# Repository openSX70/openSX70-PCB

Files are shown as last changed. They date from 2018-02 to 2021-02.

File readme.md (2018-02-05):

+ ## **What is openSX70?**

It is many things at once, but simply put, openSX70 is an open source (hardware and software) project that aims to take the SX70 beyond what is possible now in a cheap and non destructive way. 

Its main project at the moment is to make an [Arduino](https://www.arduino.cc/)-based replacement PCB (ECM in Polaroid lingo, and corresponding Arduino code to gain manual camera control, allow for double exposures, Bluetooth control and much more.
At the same time the project aims to be a hub of all things SX70 related, with documents concerning tips, repairs or hacks, like the electronic modification of your camera to accept 600-ISO film. There are other web pages about the SX70, but most seem to be abandoned. We would like to compile as many as possible resources.

+ ## **What does an openSX70 camera that a regular SX70 doesn't?**

In a nutshell: manual control of the camera:
 
 -  Manual shutter speed control. Within the limits of the camera (around 1/175th)
 -  Double/Multiple exposures.
 -  B (Bulb) mode.
 -  T mode.
 -  PC flash connector.
 -  f.8 (maximum aperture) flash operation.
 -  Optional delayed mirror operation (to avoid vibrations).
 -  Built-in shutter delay (long press on red button).
 -  Built-in optional light meter.
+ ## **Where is openSX70?**

 This is our [main webpage and repository of files](www.opensx70.com). We also have [Facebook group](https://www.facebook.com/groups/739071666267626/ "Facebook openSX70 group"). We are also on instagram and Twitter. The code and files are in [Github](https://github.com/openSX70).

+ ## **But, hasn’t this already been done?**

Yes… and no. There are at least two awesome commercial projects that accomplish something quite similar. I recommend them both. But this is the first open source project.

+ ## **So openSX70 is a product?**

Again, yes and no, since it is an open project anyone will be able to make his own pcb (as long as it has no commercial purpose).
Since we recognize that disassembling an SX70 and replacing the board is not for the faint of heart, if the project is successful and there is interest we might set up a network of associates that will do it for you. That would help us gain economies of scale, and, cover operating costs. Once the pcb is in the camera you will be able to reprogram it fairly easily as many times as you want.

+ ## **Ok, I like it, how can I get one?**

Please bear in mind that openSX70 is not a product as such, and will probably never be. Think of it as an ever improving experimental platform. As an open project, it is basically free as long as you use for non commercial purposes under [Creative Commons "Attribution-NonCommercial 4.0 International (CC BY-NC 4.0)"](https://creativecommons.org/licenses/by-nc/4.0/)
Since the process of replacement of the SX70 board is not trivial, you need special tools, and you can damage the camera in the process, parts as such will probably never be sold to general public. The board replacement is non-destructive but has to be done carefully. **See previous question about openSX70 as as product**.

+ ## **So then… how "far" ahead is the project now?**

We are quite ahead in development. We have successfully replaced the ECM of an alpha camera with an external prototype board: the“FrankenSX70”. Then we have prototyped the external control dongle. Now the electronic schematics of both the main circuit and the dongle are more or less finalised and also a preliminary design of the board has been done and some prototypes have been ordered.
For a quick reference of the status check the project page.

We are also trying to replicate and make more affordable some of the special tools needed to open and fix the SX70, and find replacements and alternatives of critical parts.

+ ## **Can I help?**

YES! We need your help, join us!
We want **YOU** to join us on the openSX70 project in any capacity that you wish, we need your help, we have to set up the openSX70 portal, we need arduino and microcontroller programmers, we need help designing the PCB, and above all, we need enthusiasts to join and build a community to propagate the project!

We want to encourage and **support** for similar commercial products and services already on the market, but specially the dedicated people that repair and improve these amazing cameras. All for the love of the SX70 camera.

If you have a skill, or maybe a repair manual, a tool, a picture of a tool, and, in general anything that might be of interest  related to the original Polaroid/SX70, and are willing to help please [contact us](mailto:help@opensx70.com), if you want to keep it confidential. We will honor your wishes, but keep in mind that we need to keep these cameras alive.

+ ## **What Open Source license do you use?**

As a legal reminder please note that the code and files is under [Creative Commons "Attribution-NonCommercial 4.0 International (CC BY-NC 4.0)" is free and open for hobbyist NON-COMMERCIAL USE.](https://creativecommons.org/licenses/by-nc/4.0/)

+ ## **How can I contact you?**

  - Press contact: opensx70 at opensx70 dot com

  - web: www.opensx70.com  

  - [Facebook (closed group)](https://goo.gl/3qjne2)

  - Twitter: @openSX70

  - instagram: openSX70
  
   - [Github project page](https://goo.gl/1A1QbY)

Tags: #openSX70 #SX70 #Polaroid #Arduino #TIP #ImpossibleProject #InstantFilm #DIY #OriginalPolaroids

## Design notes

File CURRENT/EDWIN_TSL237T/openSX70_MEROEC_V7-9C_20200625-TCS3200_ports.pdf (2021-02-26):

Atmel ATMega 328P TQFP for openSX70 Meroë TCL3200 | TIMERS
Pin Name | Camera | explanation | I/O | | arduino | DIP Pin | comment
0 (RX) | FTDI | | | | | 30 | Serial port
1 (TX) | FTDI | | | | | 31 | Serial port
2 | TCS3200 | S1-SCALING | | | | 32
3 (PWM) | Sol#1 | Solenoid #1 power | output | | | 1 | TImer 2 B:For fast PWM affects D11 & D3 | | OC2B
4 | FF | triggers flash | output | | | 2 | works with 3.3V | T0 input
5 (PWM) | TCS3200 | Light sensor 16bit counter interrupts | input | LM | Timer1 | 9 | Timer 1 lightmeter | T1input | OC0B
6 (PWM) | TCS3200 | S3-TYPE | | | | 10 | | | OC0A
7 | S5 | Stops motor both by closing and opening depeending | input | GND | | 11
8 | S3 | Initiates «Y», 40 milliseconds delay. (Power down | input | GND | | 12
9 (PWM) | TCS3200 | CHIP ENABLE | | | | 13 | | | OC1A
10 (PWM) | | | | | | | | | OC1B
11 (PWM) | Sol#2 | Solenoid #2 power | output | | MISO | 15 | TImer 2 A: For fast PWM code affects D11 & D3 | | OC2A
12 | S1 | red shutter button: Initiates exposure cycle. | input | GND | MOSI | 16 | original feeds 6V might need to change for sonar
13 | LED1 | same as built-in LED | output | | SCK | 17 | Arduino standard blink LED
A0 | S9 | Prevents firing flash if film pack counter is on «0». | input | 6V | | 23
A1 | S8 | Enables (with S7 closed) the circuitry to eject dark slide. | input | 6V | | 24
A2 | M | Motor | output | | | 25 | Starts motor through original MCC mosfet
A3 | LED2 | LED2 | | | | 26
A4 | S2 | Connects circuitry to detect flash inserted in camera. | input | GND | | 27 | moved to digital/analog for A8 dongle
A5
A6 | | | | | | 19 | analog input only
A7 | | | | | | 22 | analog input only
A Ref | | | | | | 20
Reset | | | | | Reset | 29
VCC | | | | | | 4
VCC | | | | | | 6
AVCC | | | | | | 18
GND | | | | | | 3
GND | | | | | | 5
GND | | | | | | 21
XTAL | | | | | | 7
XTAL | | | | | | 8

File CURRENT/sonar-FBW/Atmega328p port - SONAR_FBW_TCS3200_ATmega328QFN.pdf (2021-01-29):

SONAR_FBW_TCS3200_ATmega328QFN

21/05/2020

Atmel ATMega 328P QFN for openSX70 Sonar_FBW_TCS3200 | TIMERS
Pin Name | Camera | explanation | I/O | | arduino | DIP Pin | comment
0 (RX) | FTDI | | | | | 30 | Serial port
1 (TX) | FTDI | | | | | 31 | Serial port
2 | sonar | S1F FBW | output | | | 32 | control focusing via software and a high side switch
3 (PWM) | Sol#1 | Solenoid #1 power | output | | | 1 | TImer 2 B:For fast PWM affects D11 & D3 | | OC2B
4 | FF | triggers flash | output | | | 2 | works with 3.3V | T0 input
5 (PWM) | LM | Light sensor 16bit counter interrupts | input | | Timer1 | 9 | Timer 1 | T1input | OC0B
6 (PWM) | TCS3200 | TCS3200_S3 | output | | | 10 | | | OC0A
7 | S5 | Stops motor both by closing and opening depending | input | GND | | 11
8 | S3 | Initiates «Y», 40 milliseconds delay. (Power down | input | GND | | 12
9 (PWM) | TCS3200 | TCS3200_S1 | output | | | 13 | was chip enable now enabled by hardware | | OC1A
10 (PWM) | S1F | Red shutter button: pre-focus | input | 6V | | 14 | Sonar | | OC1B
11 (PWM) | Sol#2 | Solenoid #2 power | output | | MISO | 15 | TImer 2 A: For fast PWM code affects D11 & D3 | | OC2A
12 | S1T | red shutter button: Initiates exposure cycle. | input | 6V | MOSI | 16 | original feeds 6V might need to change for sonar
13 | LED1 | same as built-in LED | output | | SCK | 17 | Arduino standard blink LED
A0 | S9 | Prevents firing flash if film pack counter is on «0». | input | 6V | | 23
A1 | S8 | Enables (with S7 closed) the circuitry to eject dark slide. | input | 6V | | 24
A2 | M | Motor | output | | | 25 | Starts motor through original MCC mosfet
A3 | LED2 | LED2 | output | | | 26
A4 | S2 | Connects circuitry to detect flash inserted in camera. | input | GND | | 27 | moved to digital/analog for A8 dongle
A5 | GTD | Gone the distance @3.3V | input | 6V | | 28 | Sonar
A6 | S4 | S4@3.3V | input | | | 19 | analog input only
A7 | FT | experimental | input | | | 22 | analog input only
A Ref | | | | | | 20
Reset | | | | | Reset | 29
VCC | | | | | | 4
VCC | | | | | | 6
AVCC | | | | | | 18
GND | | | | | | 3
GND | | | | | | 5
GND | | | | | | 21
XTAL | | | | | | 7
XTAL | | | | | | 8

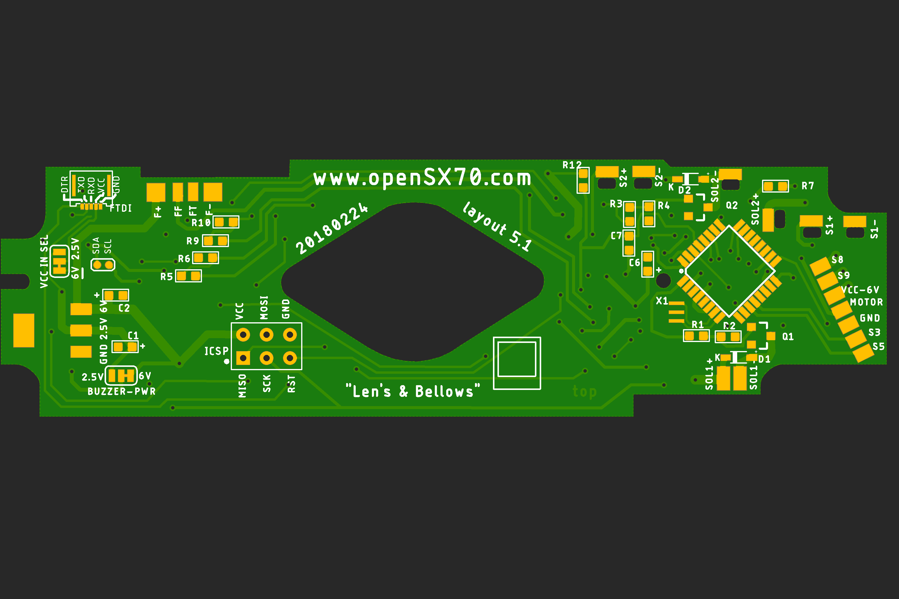
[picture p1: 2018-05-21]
CURRENT/openSX70_LENS&BELLOWS_V5.1-SEEED_20180224.png

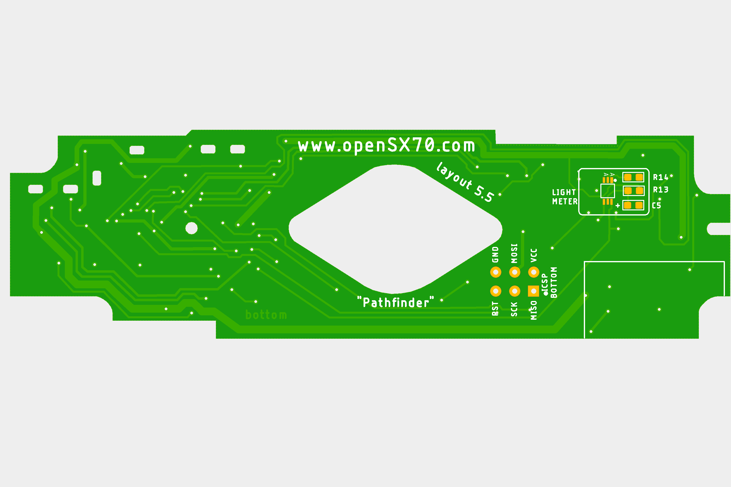
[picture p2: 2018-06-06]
CURRENT/openSX70_PATHFINDER_V5.5-SEEED_20180522-bottom-red.png

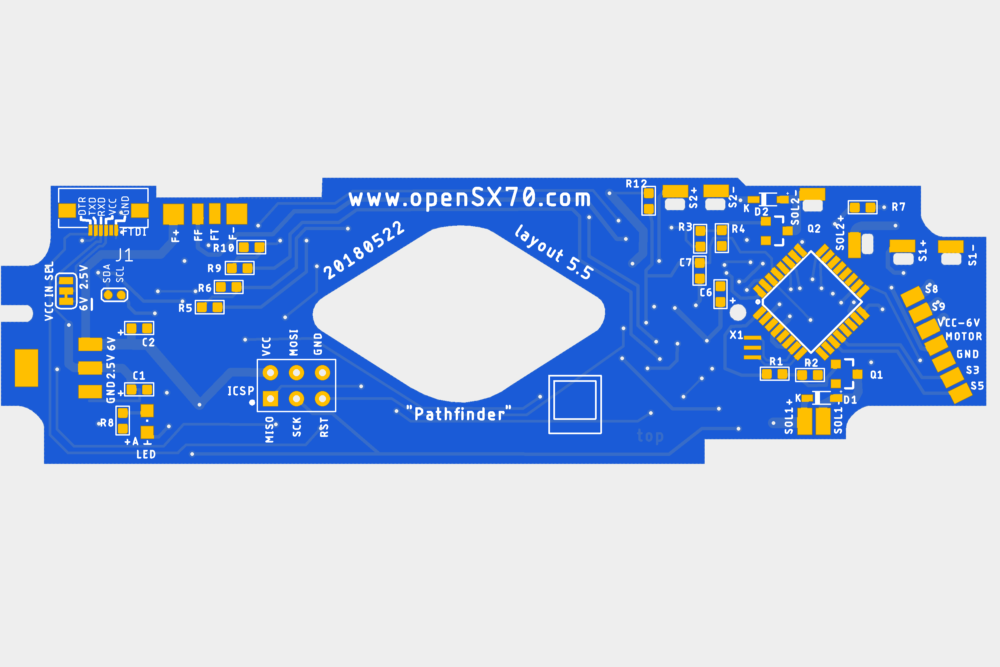
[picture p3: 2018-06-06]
CURRENT/openSX70_PATHFINDER_V5.5-SEEED_20180522-top-blue.png

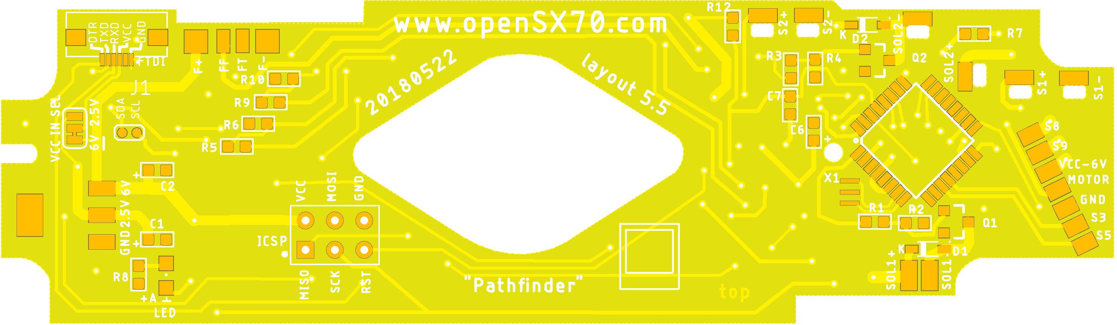
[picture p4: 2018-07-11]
CURRENT/openSX70_PATHFINDER_V5.5-SEEED_20180522-YELLOW.png

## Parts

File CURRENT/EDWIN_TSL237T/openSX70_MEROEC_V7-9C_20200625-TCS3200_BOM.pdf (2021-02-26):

BOM

Item # | *Ref Des | *Qty | Manufacturer | *Mfg Part # | Description / Value | *Package | Type | Your Instructions / Notes
1 | C1, C4 | 2 | any/open AVL | 10uF | CERAMIC-10UF-10V-10%-X5R(0603) | C0603 | SMD | any brand-name manufacturer from AVL
2 | C2, C3, C5, C6, C7, C8, C9 | 7 | any/open AVL | 100nF | CERAMIC-100NF-50V-10%-X7R(0603) | C0603 | SMD | any brand-name manufacturer from AVL
3 | R2, R4 | 2 | any/open AVL | 100K | SMD-RES-100K-5%-1/10W(0603) | R0603 | SMD | any brand-name manufacturer from AVL
4 | R1, R3, R7 | 3 | any/open AVL | 100R | SMD-RES-100R-5%-1/10W(0603) | R0603 | SMD | any brand-name manufacturer from AVL
5 | R5, R9, R12 | 3 | any/open AVL | 10K | SMD-RES-10K-1%-1/10W(0603) | R0603 | SMD | any brand-name manufacturer from AVL
6 | R6, R10 | 2 | any/open AVL | 12K | SMD-RES-12K-1%-1/10W(0603) | R0603 | SMD | any brand-name manufacturer from AVL
7 | R8, R11 | 2 | any/open AVL | 1K 1/10W | SMD-RES-1K-5%-1/10W(0603) | R0603 | SMD | any brand-name manufacturer from AVL
8 | D1, D2 | 2 | any/open AVL | 1N4148WS | 1N4148WS Series 75 V 300 mA Surface Mount Small Signal Diodes | SOD323 | SMD | Polarity marked
9 | Q1, Q2 | 2 | Alpha Omega | MOSFET-NCH-AO3404A | 5.8A/30V/35mΩ | SOT23-3 | SMD | DO NOT REPLACE MUST USE THIS
10 | J1 | 1 | Wurth Electronics | 687106183722 | WR-FPC SMT Horiztl .50mm Bott Cont 6P | 687106183722 | SMD
11 | U1 | 1 | Microchip Technology | ATMEGA328P-TQFP | ATMEGA328P_32TQFP | TQFP32 | SMD | no thermal pad implemented there are NO vias under
12 | U2 | 1 | Texas Instruments | TPS79533DCQR | Ultralow-Noise, High-PSRR, Fast, RF, 500-mA Low-Dropout Linear Regulators 6-SOT-223 -40 to 125 | SOT-223-6 | SMD | 3.3V operation
13 | X1 | 1 | Murata Electronics North America | CSTNE8M00G550000R0 | Resonators 8.0000MHz 33pF SMD | CFP95P160X100-3N | SMD | Resonators 8MHz 5%
14 | LED | 1 | Lite-On Inc. | LTST-C195TBJRKT | Blue/Red Clear | 0606 | SMD
15 | U3 | 1 | AMS | TCS3200D-TR | Light To Frequency & Light To Voltage Light to Frequency High Responsivity | SOIC8 | SMD

31

AVL (Approved Vendor
List)
TDK, Murata, Taiyo Yuden,
AVX, Panasonic, Samsung,
Vishay, ON Semiconductor,
Diodes Incorporated

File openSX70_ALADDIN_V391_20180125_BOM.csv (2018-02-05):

Part | Value | Device | Package | Description
BUZZ1 | CSET8-5G | CSET8-5G | CSET8-5G_PACKAGE
C1 | 10uF | 10UF-0603-6.3V-20% | 0603 | 10.0µF ceramic capacitors
C2 | 100nF | C-EUC0603K | C0603K | CAPACITOR, European symbol
C5 | 10uF | 10UF-0603-6.3V-20% | 0603 | 10.0µF ceramic capacitors
C6 | 100nF | C-EUC0603 | C0603 | CAPACITOR, European symbol
C7 | 0.1uF | 0.1UF-0603-25V-(+80/-20%) | 0603 | 0.1µF ceramic capacitors
D1 | 1N4148WSF | DSOD323 | SOD323 | DIODE
D2 | 1N4148WSF | DSOD323 | SOD323 | DIODE
J1 | GND | XF2L-0625-1 | XF2L-0625-1 | OMRON FPC Connector
JP1 | FTDI VCC SELECTOR | JUMPER-SMT_3_1-NC_TRACE_SILK | SMT-JUMPER_3_1-NC_TRACE_SILK | Normally closed trace jumper (1 of 2 connections)
LD11172.5V | LD1117 2.5V | LD1117-3.3 | SOT223
LED1 |  | LEDCHIPLED_0805 | CHIPLED_0805 | LED
MISO | PTR1TP08R | PTR1TP08R | TP08R | TEST PIN
MOSI | PTR1TP08R | PTR1TP08R | TP08R | TEST PIN
Q1 | 5.8A/30V/35mO | MOSFET-NCH-AO3404A | SOT23-3 | N-channel MOSFETs
Q2 | 5.8A/30V/35mO | MOSFET-NCH-AO3404A | SOT23-3 | N-channel MOSFETs
R1 | 100R | R-US_R0603 | R0603 | RESISTOR, American symbol
R2 | 100K | R-US_R0603 | R0603 | RESISTOR, American symbol
R3 | 100R | R-US_R0603 | R0603 | RESISTOR, American symbol
R4 | 100K | R-US_R0603 | R0603 | RESISTOR, American symbol
R5 | 15K | R-US_R0603 | R0603 | RESISTOR, American symbol
R6 | 10K | R-US_R0603 | R0603 | RESISTOR, American symbol
R7 | 100R | R-US_R0603 | R0603 | RESISTOR, American symbol
R8 | 1K | R-US_R0603 | R0603 | RESISTOR, American symbol
R9 | 15K | R-US_R0603 | R0603 | RESISTOR, American symbol
R10 | 10K | R-US_R0603 | R0603 | RESISTOR, American symbol
R12 | 10K | R-US_R0603 | R0603 | RESISTOR, American symbol
R13 | 1K | R-US_R0603 | R0603 | RESISTOR, American symbol
R14 | 4K7 | R-US_R0603 | R0603 | RESISTOR, American symbol
S1+ | SX70-S-PAD-NEW | SX70-S-PAD-NEW | SX70-S-PAD2
S1- | SX70-S-PAD-NEW | SX70-S-PAD-NEW | SX70-S-PAD2
S2+ | SX70-S-PAD-NEW | SX70-S-PAD-NEW | SX70-S-PAD2
S2- | SX70-S-PAD-NEW | SX70-S-PAD-NEW | SX70-S-PAD2
SCK | PTR1TP08R | PTR1TP08R | TP08R | TEST PIN
SCL | PTR1TP08R | PTR1TP08R | TP08R | TEST PIN
SDA | PTR1TP08R | PTR1TP08R | TP08R | TEST PIN
SOL1 | SX70-SOLENOID1-2PADS | SX70-SOLENOID1-2PADS | SX70-SOLENOID1-2
SOL2+ | SX70-S-PAD-NEW | SX70-S-PAD-NEW | SX70-S-PAD2
SOL2- | SX70-S-PAD-NEW | SX70-S-PAD-NEW | SX70-S-PAD2
TP-3.3V | SX70-S-PAD-NEW | SX70-S-PAD-NEW | SX70-S-PAD2
TP-6V | SX70-S-PAD-NEW | SX70-S-PAD-NEW | SX70-S-PAD2
TP-GND | SX70-S-PAD-NEW | SX70-S-PAD-NEW | SX70-S-PAD2
U$1 | SX70-7-PAD | SX70-7-PAD | SX70-7-PAD
U$2 | FFA | SX70-FFA-PAD | FFA-PAD-PACKAGE
U1 | ATMEGA328P_TQFP | ATMEGA328P_TQFP | TQFP32-08 | Popular 328P in QFP
U3 | BH1750FVI-TR | BH1750FVI-TR | SOTFL50P300X75-6N | Light to Digital Ambient Light Sensor Digital O/P 1lux to 65535lux 6-Pin WSOF Embossed T/R
Y1 | CSTCE16M0V53-R0 | CSTCE16M0V53-R0 | CFP95P160X100-3N | Ceramic Resonator 16MHz ±0.5% (Tol) ±0.3% (Stability) 15pF 40Ohm 3-Pin CSMD T/R

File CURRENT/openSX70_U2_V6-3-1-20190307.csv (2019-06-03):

Qty | Value | Device | Package | Parts | Description
1 | 1000pF | CERAMIC-100NF-50V-10%-X7R(0603) | C0603 | C3 | 302010138
2 | 100K 1/10W | SMD-RES-100K-5%-1/10W(0603) | R0603 | R2, R4 | 301010089
3 | 100R | SMD-RES-100R-5%-1/10W(0603) | R0603 | R1, R3, R7 | 301010090
3 | 100nf | CERAMIC-100NF-50V-10%-X7R(0603) | C0603 | C2, C6, C7 | 302010138
4 | 10K | SMD-RES-10K-1%-1/10W(0603) | R0603 | R6, R8, R10, R12 | 301010299
1 | 10uf | CERAMIC-10UF-10V-10%-X5R(0603) | C0603 | C1 | 302010103
2 | 15K 1/10W | SMD-RES-15K-1%-1/10W(0603) | R0603 | R5, R9 | 301010241
1 | 1K 1/10W | SMD-RES-1K-5%-1/10W(0603) | R0603 | R11 | 301010291
2 | 1N4148WSF | 1N4148WS | SODFL2512X100N | D1, D2 | 1N4148WS Series 75 V 300 mA Surface Mount Small Signal Diodes - SOD-323F
2 | 5.8A/30V/35mΩ | MOSFET-NCH-AO3404A | SOT23-3 | Q1, Q2 | N-channel MOSFETs
1 | 687106183722 | 687106183722 | 687106183722 | J1 | 687106183722
1 | AD654 | AD654 | SOIC8 | IC1 | Low Cost Monolithic Voltage-to-Frequency Converter
1 | ATMEGA328P_TQFP | ATMEGA328P_TQFP | TQFP32-08 | U1 | Popular 328P in QFP
1 | CSTCE8M00G52Z-R0 | CSTCE16M0V53-R0 | CFP95P160X100-3N | Y1 | Ceramic Resonator 16MHz ±0.5% (Tol) ±0.3% (Stability) 15pF 40Ohm 3-Pin CSMD T/R
1 | FFA | SX70-FFA-PAD | FFA-PAD-PACKAGE | U$2
1 | ICSP | ICSP | H2X3-2.54 | ICSP
1 | LD1117 2.5V | LD1117-3.3 | SOT223 | LD11172.5V
1 | LTST-C195KGJRKT | LTST-C195KGJRKT | LTST-BILED-15X16 | U$4
1 | SX70-7-PAD | SX70-7-PAD | SX70-7-PAD-PROPER | U$1
6 | SX70-S-PAD-NEW | SX70-S-PAD-NEW | SX70-S-PAD2 | S1+, S1-, S2+, S2-, SOL2+, SOL2-
1 | SX70-SOLENOID1-2PADS | SX70-SOLENOID1-2PADS | SX70-SOLENOID1-2 | SOL1
1 | TEST-POINT3X4 | TEST-POINT3X4 | PAD.03X.04 | TP1 | SparkFun Test Points
1 | VBPW34S | VBPW34S | SOD6439X130N | D3 | VBPW34SR Series 60 V 940 nm 50 mA 215 mW Surface Mount Silicon PIN Photodiode

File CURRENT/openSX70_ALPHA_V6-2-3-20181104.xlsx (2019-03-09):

Parts | Qty | Value | Device | Package | Description
R2, R4 | 2 | 100K 1/10W | SMD-RES-100K-5%-1/10W(0603) | R0603 | 301010089
R1, R3, R7 | 3 | 100R | SMD-RES-100R-5%-1/10W(0603) | R0603 | 301010090
R11 | 1 | V3-SCL | PHOTODIODE | R0603 | V3-SCL
R14 | 1 | V1 | PHOTODIODE | R0603 | V1
R15 | 1 | V2-SDA | PHOTODIODE | R0603 | V2-SDA
R5, R9 | 2 | 15K 1/10W | SMD-RES-15K-1%-1/10W(0603) | R0603 | 301010241
R16 | 1 | 1K 1/10W | SMD-RES-1K-5%-1/10W(0603) | R0603 | 301010291
R6, R10, R12 | 3 | 10K | SMD-RES-10K-1%-1/10W(0603) | R0603 | 301010299
C2, C3, C6, C7 | 4 | 100nf | CERAMIC-100NF-50V-10%-X7R(0603) | C0603 | 302010138
C1 | 1 | 10uf | CERAMIC-10UF-10V-10%-X5R(0603) | C0603 | 302010103
D1, D2 | 2 | 1N4148WSF | 1N4148WS | SODFL2512X100N | 1N4148WS Series 75 V 300 mA Surface Mount Small Signal Diodes - SOD-323F
D3 | 1 | SFH2430 | OSRAM SFH2430
Q1, Q2 | 2 | 5.8A/30V/35 | MOSFET-NCH-AO3404A | SOT23-3 | N-channel MOSFETs
J1 | 1 | FPC 6-way |  | FPC | CONN FFC BTM 6POS 0.5MM SMD R/A
U1 | 1 | ATMEGA328P_TQFP | ATMEGA328P_TQFP | TQFP32-08 | Popular 328P in QFP
X1 | 1 | CSTCE8M00G52Z-R0 | CSTCE16M0V53-R0 | CFP95P160X100-3N
U$3 | 1 | DUAL-LED-0603-BIS | DUAL-LED-0603-BIS | 0603 | Bi-Color LED
LD11172.5V | 1 | LD1117 2.5V | LD1117-2.5 | SOT223 | 2.5V Regulator

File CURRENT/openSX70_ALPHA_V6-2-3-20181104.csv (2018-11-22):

Parts | Qty | Value | Device | Package | Description
R2, R4 | 2 | 100K 1/10W | SMD-RES-100K-5%-1/10W(0603) | R0603 | 301010089
R1, R3, R7 | 3 | 100R | SMD-RES-100R-5%-1/10W(0603) | R0603 | 301010090
R11 | 1 |  | V3-SCL |  | PHOTODIODE
R14 | 1 |  | V1 |  | PHOTODIODE
R15 | 1 |  | V2-SDA |  | PHOTODIODE
R5, R9 | 2 | 15K 1/10W | SMD-RES-15K-1%-1/10W(0603) | R0603 | 301010241
R16 | 1 | 1K 1/10W | SMD-RES-1K-5%-1/10W(0603) | R0603 | 301010291
R6, R10, R12 | 3 | 10K | SMD-RES-10K-1%-1/10W(0603) | R0603 | 301010299
C2, C3, C6, C7 | 4 | 100nf | CERAMIC-100NF-50V-10%-X7R(0603) | C0603 | 302010138
C1 | 1 | 10uf | CERAMIC-10UF-10V-10%-X5R(0603) | C0603 | 302010103
D1, D2 | 2 | 1N4148WSF | 1N4148WS | SODFL2512X100N | 1N4148WS Series 75 V 300 mA Surface Mount Small Signal Diodes - SOD-323F
D3 | 1 | VBPW34S | VBPW34S | SOD6439X130N | VBPW34SR Series 60 V 940 nm 50 mA 215 mW Surface Mount Silicon PIN Photodiode
Q1, Q2 | 2 | 5.8A/30V/35mΩ | MOSFET-NCH-AO3404A | SOT23-3 | N-channel MOSFETs
J1 | 1 | 6,87106E+11 | 6,87106E+11 | 6,87106E+11 | 6,87106E+11
U1 | 1 | ATMEGA328P_TQFP | ATMEGA328P_TQFP | TQFP32-08 | Popular 328P in QFP
X1 | 1 | CSTCE8M00G52Z-R0 | CSTCE16M0V53-R0 | CFP95P160X100-3N | Ceramic Resonator 16MHz ±0.5% (Tol) 0.3% (Stability) 15pF 40Ohm 3-Pin CSMD T/R
U$3 | 1 | DUAL-LED-0603-BIS | DUAL-LED-0603-BIS | LED_APHB1608SYKSURKC
LD11172.5V | 1 | LD1117 2.5V | LD1117-3.3 | SOT223

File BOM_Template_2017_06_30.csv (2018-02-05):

Designator | Manufacturer Part Number | Quantity
C1,C2,C3,C4,C5 | RHA0J471MCN1GS | 5
A1,A4 | 318020010 | 2
D1 | CYBLE-014008-00 | 1

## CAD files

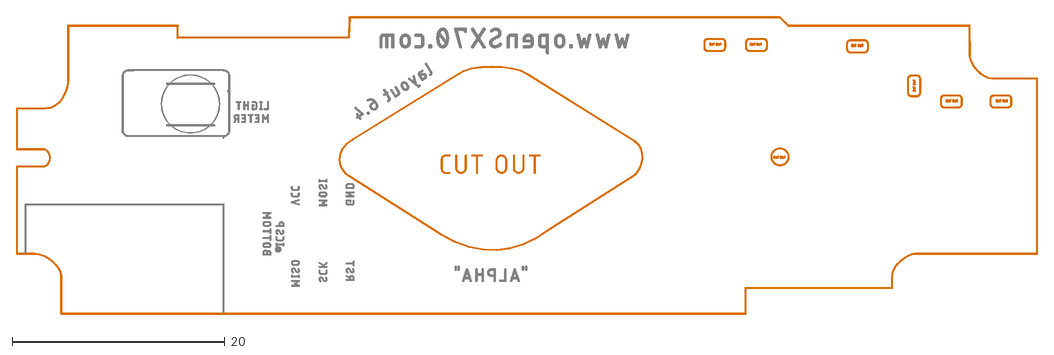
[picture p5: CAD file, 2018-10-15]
CURRENT/openSX70_ALPHA_V6.4-20181011.dxf
96.0 x 28.0

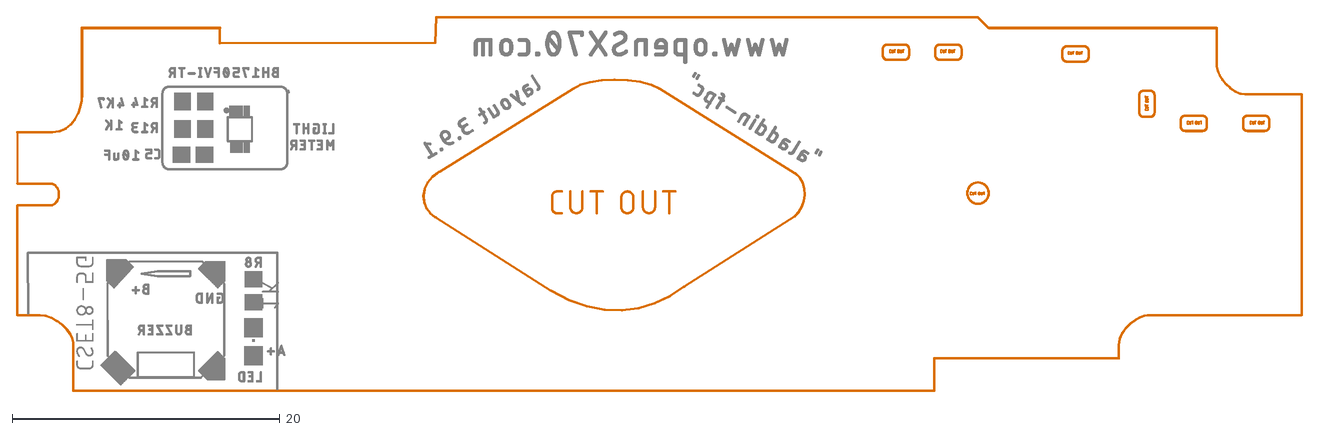
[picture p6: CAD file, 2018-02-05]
openSX70_ALADDIN_V391_20180125-bottom.dxf
96.0 x 28.0

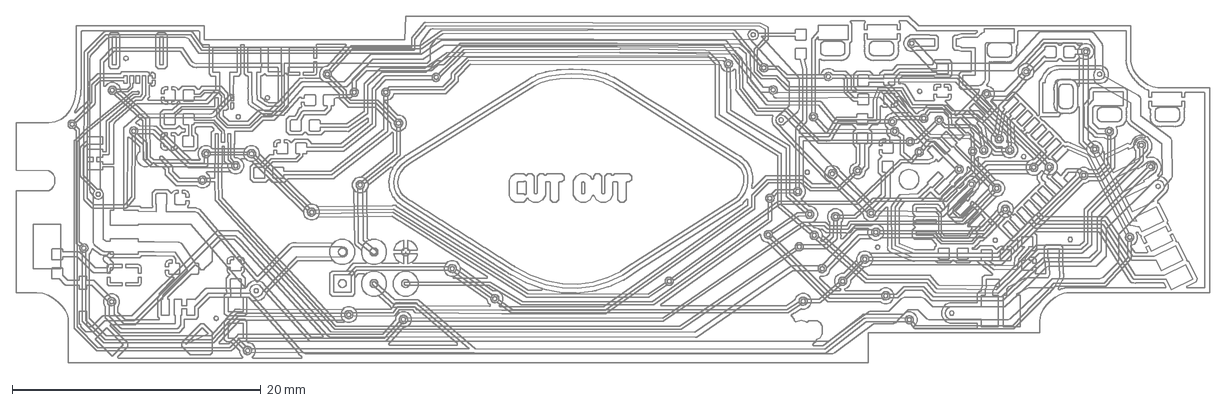
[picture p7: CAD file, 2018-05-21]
CURRENT/openSX70_LENS&BELLOWS_V5.1-SEEED_20180224.dxf
95.9 x 27.9 mm

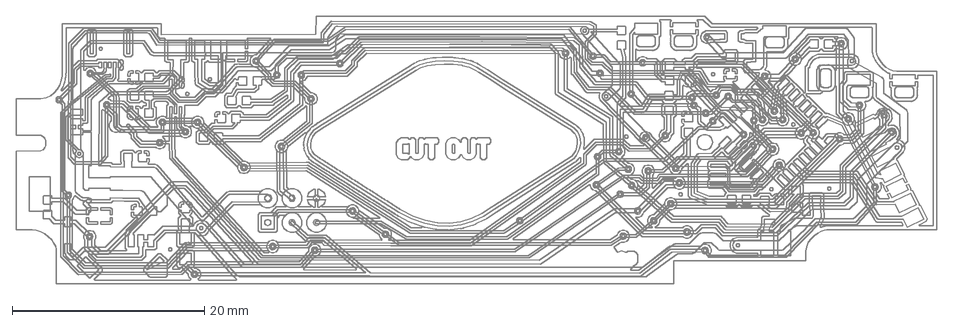
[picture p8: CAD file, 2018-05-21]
CURRENT/openSX70_LENS&BELLOWS_V5.1-SEEED_20180224-top.dxf
95.9 x 27.9 mm

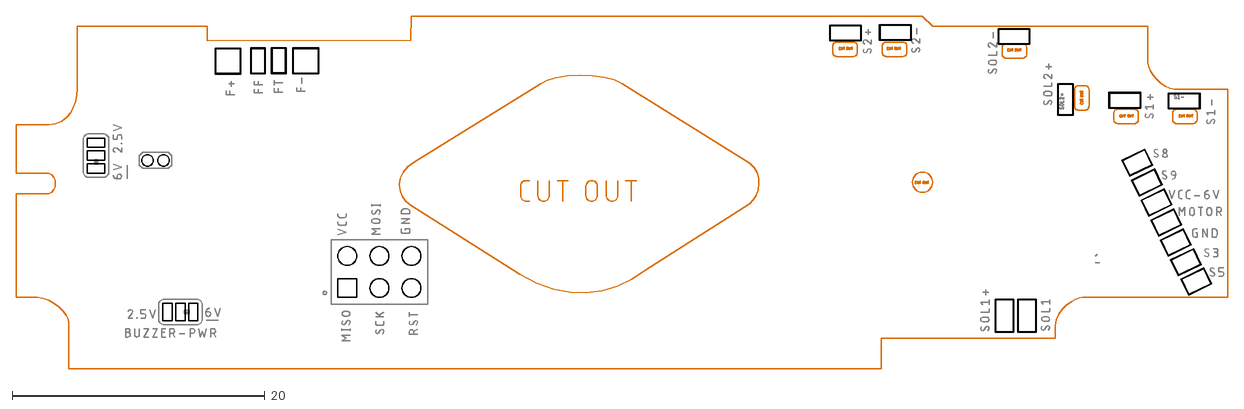
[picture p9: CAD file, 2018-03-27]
CURRENT/outline-ICSP-all.dxf
95.9 x 27.9

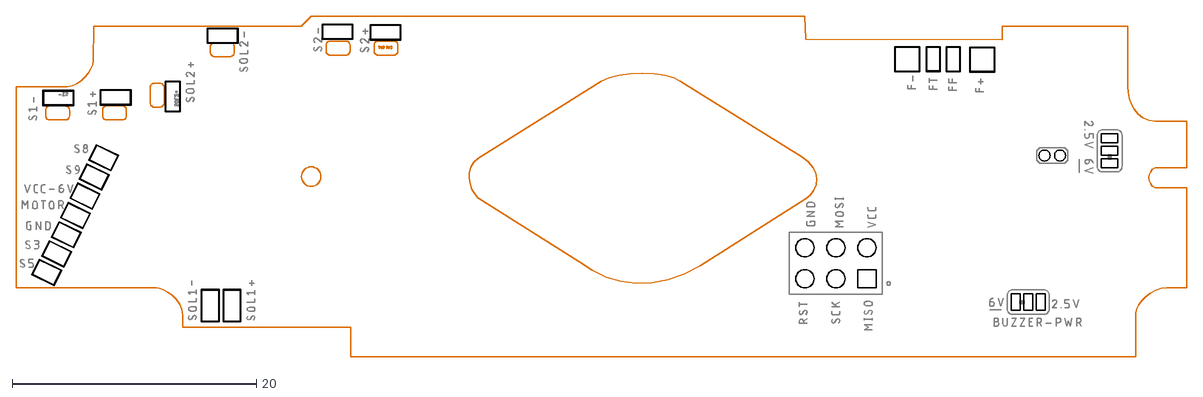
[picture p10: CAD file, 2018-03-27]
CURRENT/outline-ICSP-all_mirror.dxf
95.9 x 27.9

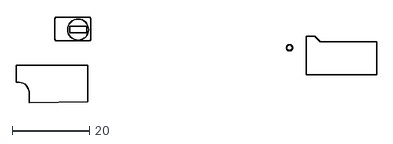
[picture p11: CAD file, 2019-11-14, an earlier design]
OLD/PCB_outline-SonarV3_bDOCU_.dxf
93.6 x 22.2

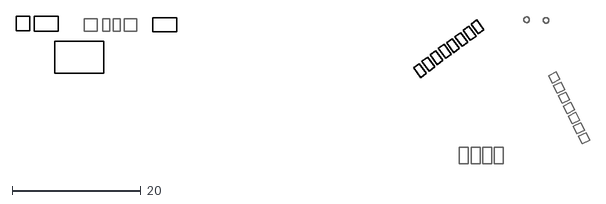
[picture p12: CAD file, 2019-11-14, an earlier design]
OLD/PCB_outline-SonarV2_tDOCU.dxf
89.0 x 22.9

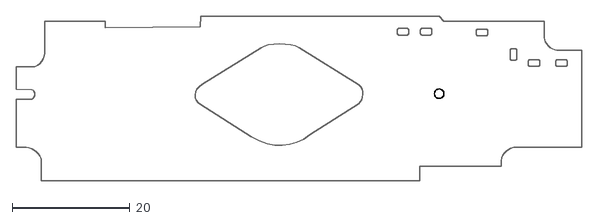
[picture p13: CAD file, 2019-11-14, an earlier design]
OLD/PCB_outline-SonarV3_NEW_HOLE.dxf
95.9 x 27.9

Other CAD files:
CURRENT/openSX70_LENS&BELLOWS_V5.2-SEEED_20180226.dxf
OLD/manufactured-LENSandBELLOWS/openSX70_LENS&BELLOWS_V5.2-SEEED_20180226.dxf

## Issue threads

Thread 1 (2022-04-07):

Which PCB for which camera?

pkoryzna, 2022-04-07:
I am having a hard time figuring out which board files are intended for which camera models - in `CURRENT` directory there's three to choose from - is there a guide that explains it?

zanepollard, 2022-04-07:
@pkoryzna Edwin and Meroe are Alpha style boards for Alpha model cameras. Sonar-FBW is for sonar model cameras. Other models are not supported in these board revisions.

@openSX70 Could you close this issue or add me to the contributor section of this repo? I only have access to the main code repo.

pkoryzna, 2022-04-10:
>Edwin and Meroe are Alpha style boards for Alpha model cameras.

Okay, the camera I would like to convert is an Alpha model, according to the film door and calculator here https://mint-camera.com/en/polaroid-sx70/serial_number_calculator/

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

Which `.brd` file will fit my camera?

I'm planning to order the PCBs and stencils from EU, most likely Aisler if that matters

openSX70, 2022-04-10:
Hey Patryk!

First of all… the f***k? use the openSX70 serial calculator!

https://opensx70.com/calculator/

Second, I think Aisler doesn’t do .6mm boards that Are needed. I tried.

As for the boards, for alpha you can use the TQFP design, the sonar-fbw2 will do alpha as well but the qfn chip is a bitch, but doable. I think there’s no qfn counterfeits. All in all the atmega328p is impossible to find at the moment. Do you have some? I mean, I don’t even find for prototyping a few boards… quote me 50us…

If you have any atmegas I might be able to send you a few bare PCBs.

Have a great day

Joaquín

El 10 abr 2022, a las 4:44 p. m., Patryk Koryzna ***@***.***> escribió:

5D925643370

pkoryzna, 2022-04-10:
>First of all… the f***k? use the openSX70 serial calculator!
will keep that in mind ;-)

>Second, I think Aisler doesn’t do .6mm boards that Are needed. I tried.
can you recommend any EU-based service that could get it done?

>All in all the atmega328p is impossible to find at the moment

actually I haven't even checked the part availability since I didn't know which board I should use

maybe I could harvest it from some arduino boards I have around the house, but I don't have the tools for that (I was planning to get a hot plate for soldering the parts for this project specifically)

I suppose I gotta put this project on ice for now until I can source the atmega :/

openSX70, 2022-04-10:
<!--
/* Font Definitions */
@font-face
	{font-family:"Cambria Math";
	panose-1:2 4 5 3 5 4 6 3 2 4;}
@font-face
	{font-family:Calibri;
	panose-1:2 15 5 2 2 2 4 3 2 4;}
/* Style Definitions */
p.MsoNormal, li.MsoNormal, div.MsoNormal
	{margin:0cm;
	font-size:11.0pt;
	font-family:"Calibri",sans-serif;
	mso-fareast-language:EN-US;}
span.EmailStyle17
	{mso-style-type:personal-compose;
	font-family:"Calibri",sans-serif;
	color:windowtext;}
.MsoChpDefault
	{mso-style-type:export-only;
	font-family:"Calibri",sans-serif;
	mso-fareast-language:EN-US;}
@page WordSection1
	{size:612.0pt 792.0pt;
	margin:70.85pt 3.0cm 70.85pt 3.0cm;}
div.WordSection1
	{page:WordSection1;}
-->

openSX70, 2022-05-09:
J

pkoryzna, 2023-04-24:
it's been a while, the PCB in my SX70s are going a bit wonky - has parts availability improved? any way to obtain an assembled board in 2023 yet? 😄

cheers

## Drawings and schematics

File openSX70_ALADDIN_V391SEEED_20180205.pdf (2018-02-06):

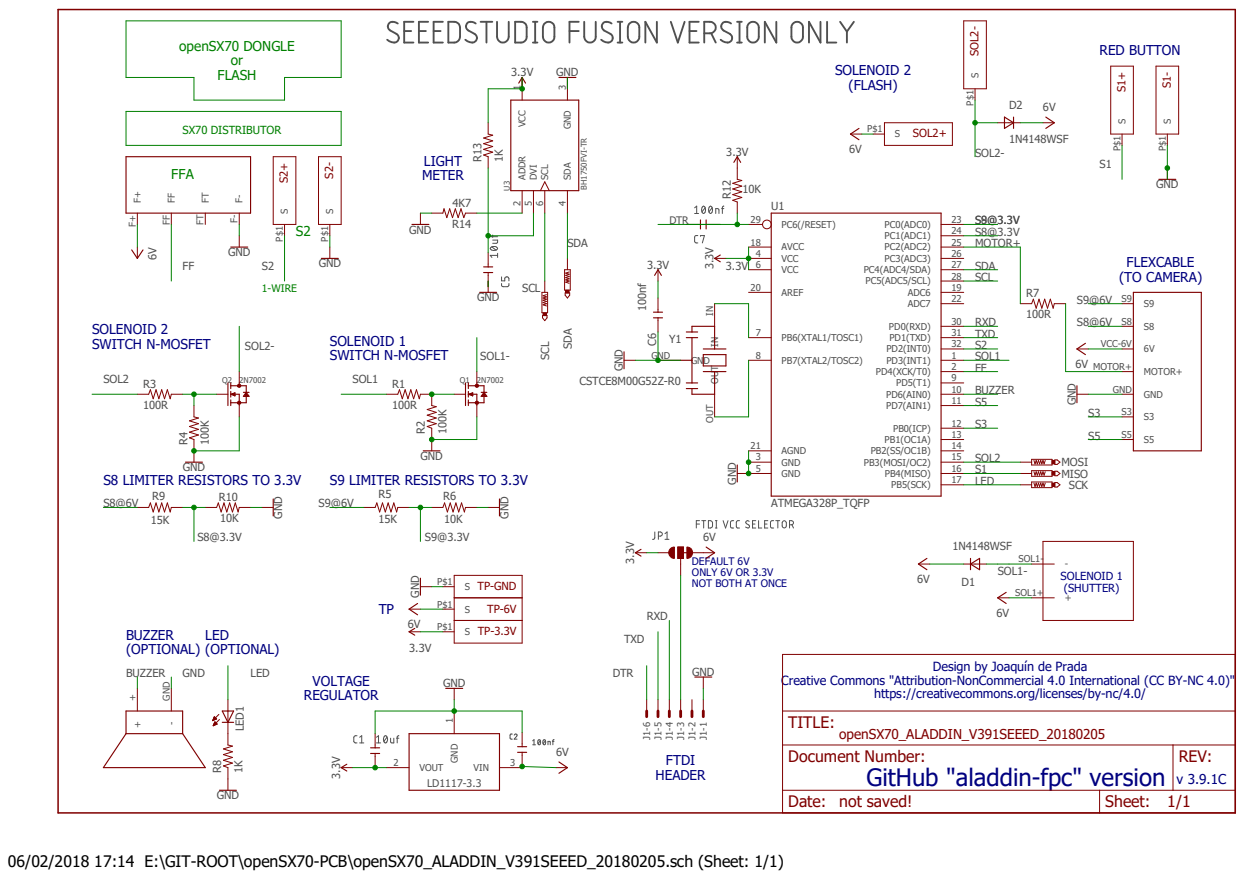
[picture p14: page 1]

DEFAULT 6V
ONLY 6V OR 3.3V
NOT BOTH AT ONCE

Design by Joaquín de Prada

Creative Commons "Attribution-NonCommercial 4.0 International (CC BY-NC 4.0)"

https://creativecommons.org/licenses/by-nc/4.0/

Document Number: GitHub "aladdin-fpc" version | REV: v 3.9.1C

Date: not saved! | Sheet: 1/1

06/02/2018 17:14 E:\GIT-ROOT\openSX70-PCB\openSX70_ALADDIN_V391SEEED_20180205.sch (Sheet: 1/1)

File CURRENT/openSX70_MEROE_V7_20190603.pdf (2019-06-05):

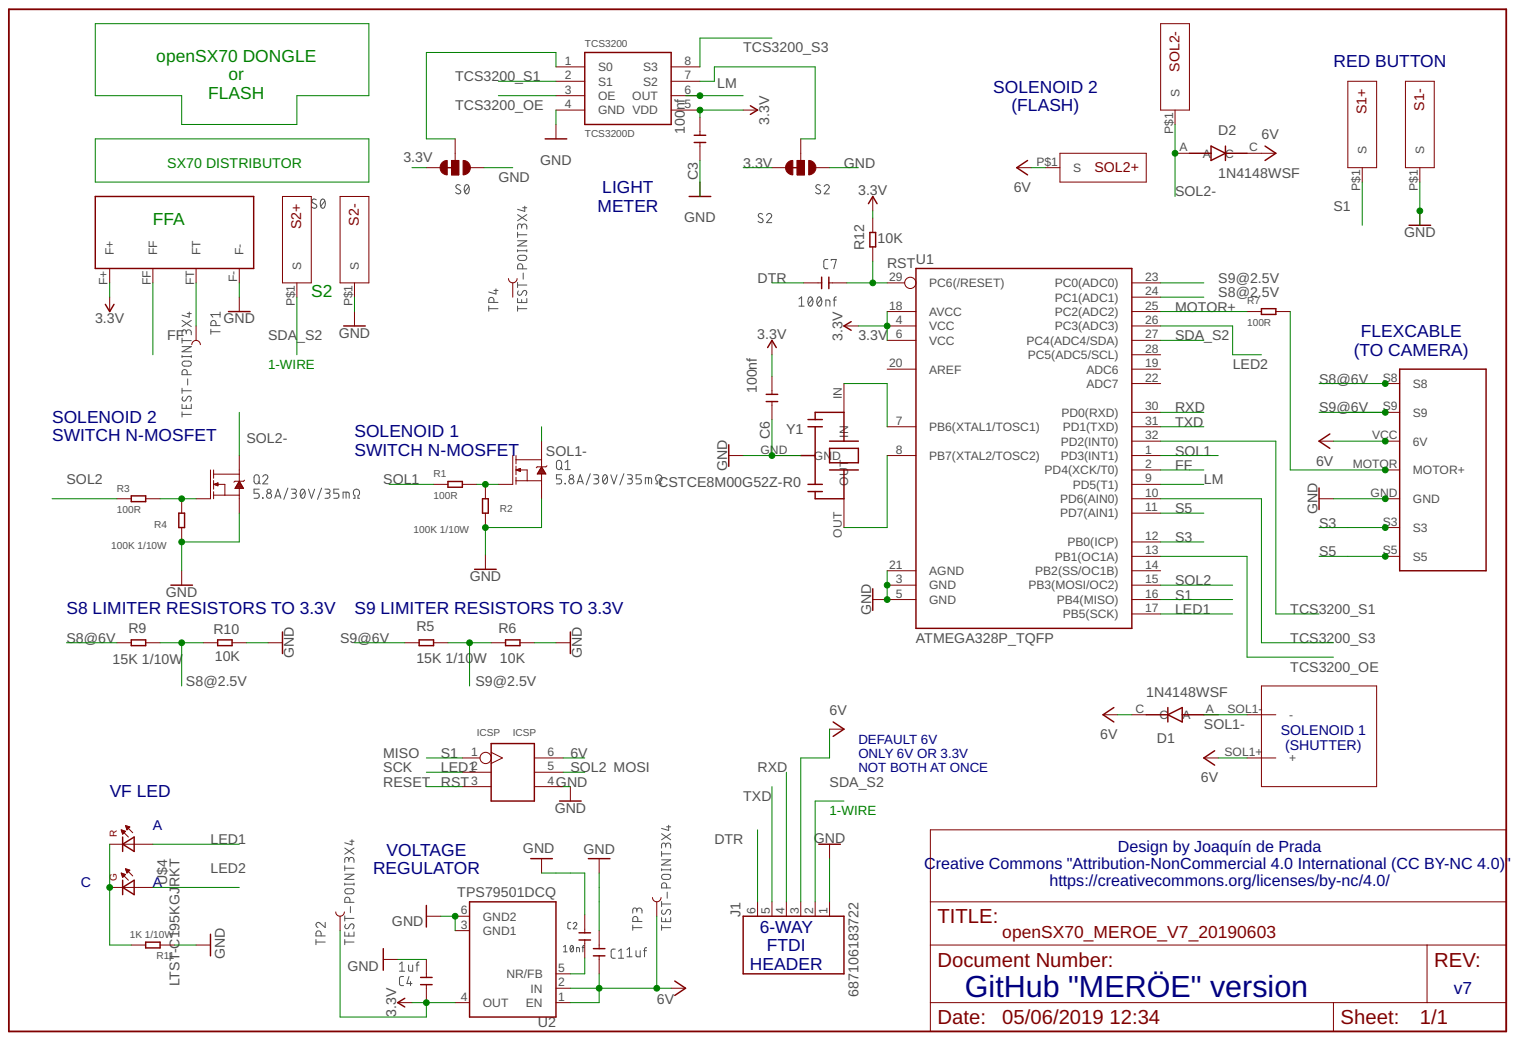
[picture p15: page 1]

IN OUT OUT GND GNDY1

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

Document Number: GitHub "MERÖE" version | REV: v7

Date: 05/06/2019 12:34 | Sheet: 1/1

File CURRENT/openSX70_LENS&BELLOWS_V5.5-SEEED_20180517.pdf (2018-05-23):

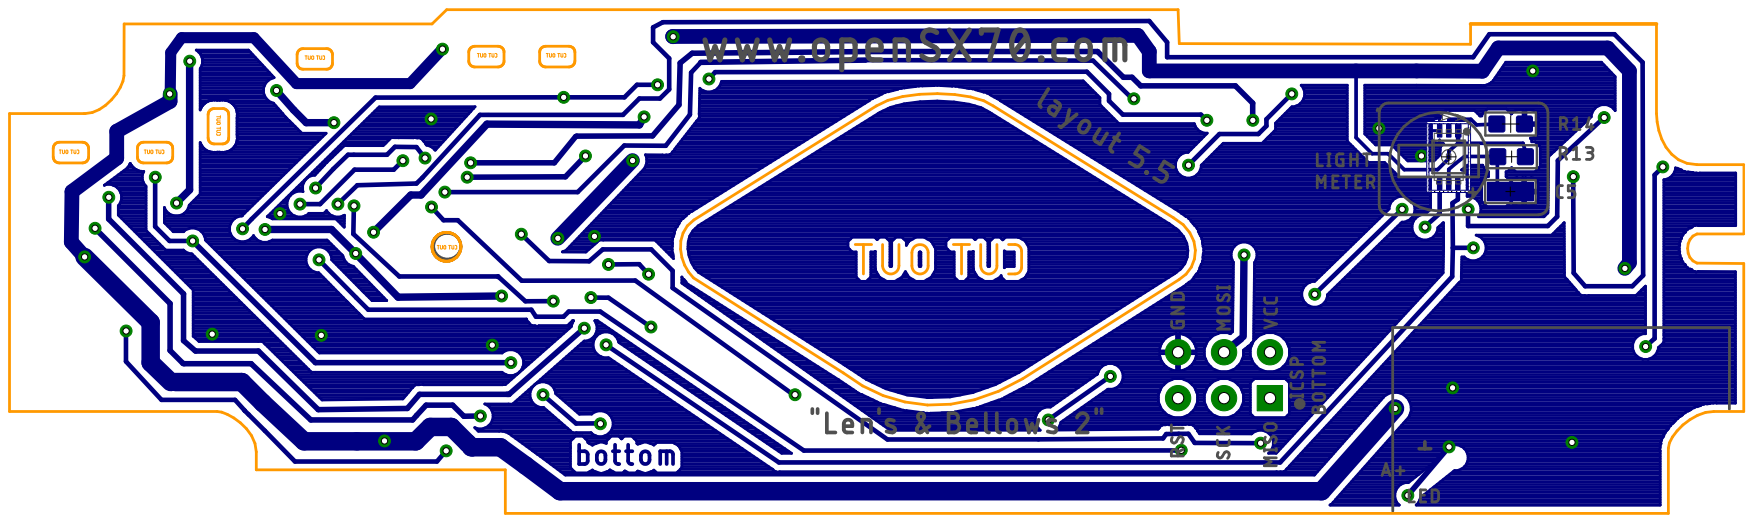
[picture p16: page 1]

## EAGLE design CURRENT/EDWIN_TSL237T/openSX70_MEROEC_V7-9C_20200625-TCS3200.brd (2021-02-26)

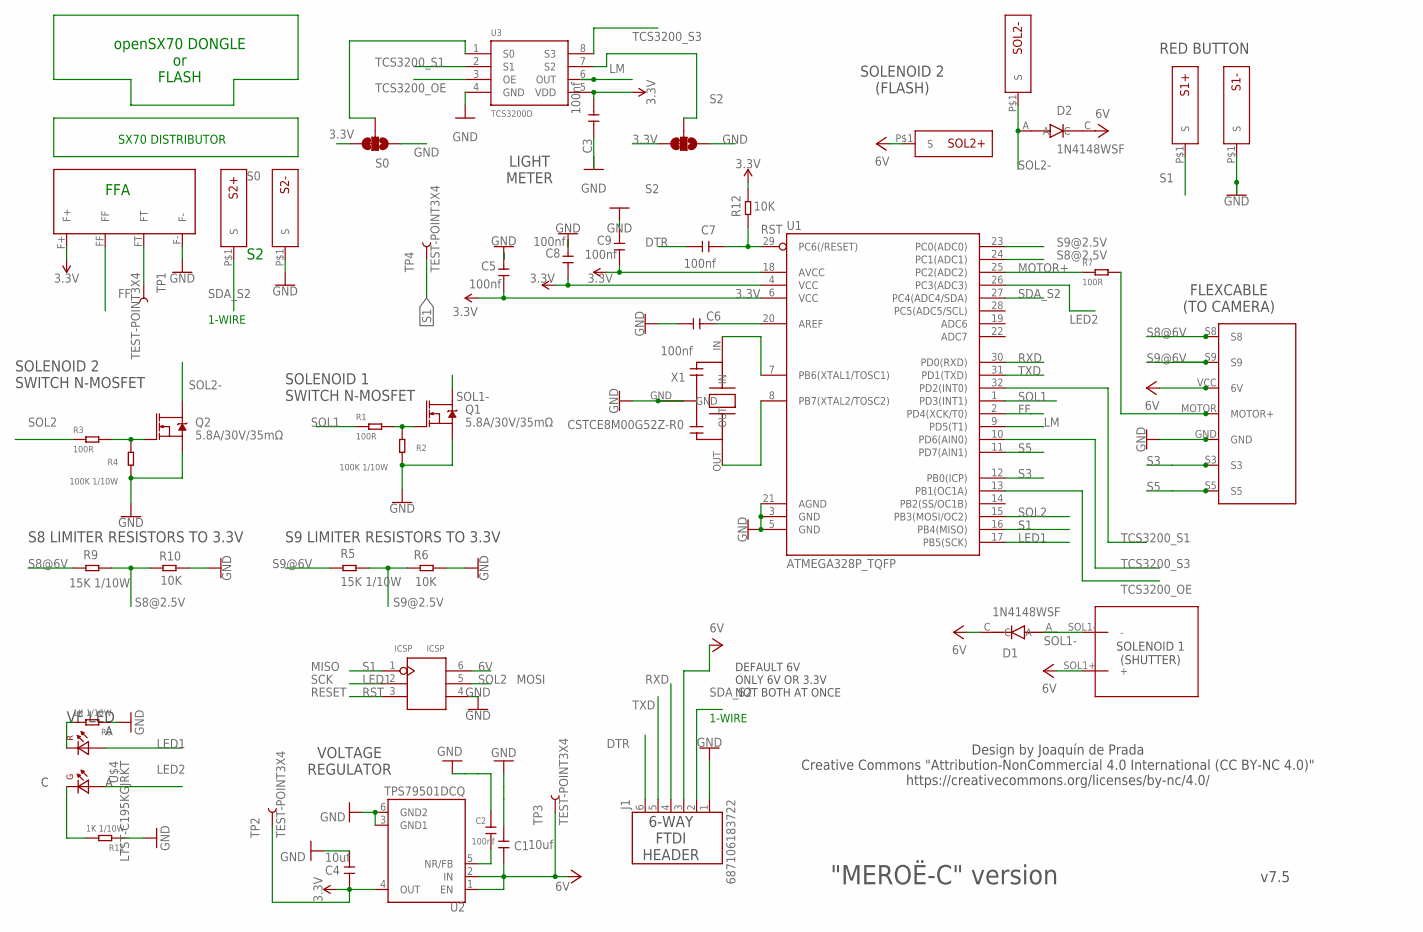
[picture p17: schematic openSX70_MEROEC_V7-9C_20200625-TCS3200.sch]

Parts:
C1, C4: 10uf; C0603
C2, C3, C5, C6, C7, C8, C9: 100nf; C0603
D1, D2: 1N4148WSF; SODFL2512X100N
ICSP: ICSP; H2X3-2.54
J1: 687106183722
Q1, Q2: 5.8A/30V/35mΩ; SOT23-3
R1, R3, R7: 100R; R0603
R2, R4: 100K 1/10W; R0603
R5, R9: 15K 1/10W; R0603
R6, R10, R12: 10K; R0603
R8, R11: 1K 1/10W; R0603
S0: S0; SMT-JUMPER_3_1-NC_TRACE_SILK
S1+, S1-, S2+, S2-: SX70-S-PAD-NEW; SX70-S-PAD2
S2: S2; SMT-JUMPER_3_1-NC_TRACE_SILK
SOL1: SX70-SOLENOID1-2PADS; SX70-SOLENOID1-2
SOL2+, SOL2-: SX70-S-PAD-NEW; SX70-S-PAD2
TP1, TP2, TP3, TP4: TEST-POINT3X4; PAD.03X.04
U1: ATMEGA328P_TQFP; TQFP32-08
U2: TPS79501DCQ; SOT127P706X180-6N
U3: TCS3200D; SOIC8
U$1: SX70-7-PAD; SX70-7-PAD-PROPER
U$2: FFA; FFA-PAD-PACKAGE
U$4: LTST-C195KGJRKT; LTST-BILED-15X16
X1: CSTCE8M00G52Z-R0; CFP95P160X100-3N

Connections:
3.3V: C3.1, C4.2, C5.1, C8.1, C9.1, R12.2, S0.3, S2.3, TP2.P$1, U1.4 (VCC), U1.6 (VCC), U1.18 (AVCC), U2.4 (OUT), U3.5 (VDD), U$2.F+
6V: C1.2, D1.C, D2.C, ICSP.6 (VCC), J1.3 (4), SOL1.SOL1+ (+), SOL2+.P$1, TP3.P$1, U2.1 (EN), U2.2 (IN), U$1.VCC (6V)
DTR: C7.1, J1.6 (1)
FF: U1.2 (PD4(XCK/T0)), U$2.FF
GND: C1.1, C2.1, C3.2, C4.1, C5.2, C6.1, C8.2, C9.2, ICSP.4 (GND), J1.1 (6), Q1.2 (S), Q2.2 (S), R2.1, R4.1, R6.2, R8.1, R10.2, R11.1, S0.1, S1-.P$1, S2.1, S2-.P$1, U1.3 (GND), U1.5 (GND), U1.21 (AGND), U2.3 (GND1), U2.6 (GND2), U3.4 (GND), U$1.GND, U$2.F-, X1.GND
LED1: ICSP.2 (SCK), U1.17 (PB5(SCK)), U$4.P$2 (A2)
LED2: U1.26 (PC3(ADC3)), U$4.P$1 (A1)
LM: U1.9 (PD5(T1)), U3.6 (OUT)
MOTOR+: R7.1, U1.25 (PC2(ADC2))
MOTOR-HEADER: R7.2, U$1.MOTOR (MOTOR+)
unnamed: Q1.1 (G), R1.2, R2.2
unnamed: C6.2, U1.20 (AREF)
unnamed: Q2.1 (G), R3.2, R4.2
unnamed: U1.7 (PB6(XTAL1/TOSC1)), X1.IN
unnamed: TP1.P$1, U$2.FT
unnamed: U1.8 (PB7(XTAL2/TOSC2)), X1.OUT
unnamed: S0.2, U3.1 (S0)
unnamed: S2.2, U3.7 (S2)
unnamed: R8.2, U$4.P$4 (K2)
unnamed: C2.2, U2.5 (NR/FB)
unnamed: R11.2, U$4.P$3 (K1)
RST: C7.2, ICSP.3 (RST), R12.1, U1.29 (PC6(/RESET))
RXD: J1.4 (3), U1.30 (PD0(RXD))
S1: ICSP.1 (MISO), S1+.P$1, TP4.P$1, U1.16 (PB4(MISO))
S3: U1.12 (PB0(ICP)), U$1.S3
S5: U1.11 (PD7(AIN1)), U$1.S5
S8@2.5V: R9.2, R10.1, U1.24 (PC1(ADC1))
S8@6V: R9.1, U$1.S8
S9@2.5V: R5.2, R6.1, U1.23 (PC0(ADC0))
S9@6V: R5.1, U$1.S9
SDA_S2: J1.2 (5), S2+.P$1, U1.27 (PC4(ADC4/SDA))
SOL1: R1.1, U1.1 (PD3(INT1))
SOL1-: D1.A, Q1.3 (D), SOL1.SOL1- (-)
SOL2: ICSP.5 (MOSI), R3.1, U1.15 (PB3(MOSI/OC2))
SOL2-: D2.A, Q2.3 (D), SOL2-.P$1
TCS3200_OE: U1.13 (PB1(OC1A)), U3.3 (OE)
TCS3200_S1: U1.32 (PD2(INT0)), U3.2 (S1)
TCS3200_S3: U1.10 (PD6(AIN0)), U3.8 (S3)
TXD: J1.5 (2), U1.31 (PD1(TXD))

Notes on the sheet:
1-WIRE
FFA
LIGHT METER
FLEXCABLE (TO CAMERA)
RED BUTTON
SOLENOID 1 (SHUTTER)
SOLENOID 2 (FLASH)
6-WAY FTDI HEADER
VOLTAGE REGULATOR
S8 LIMITER RESISTORS TO 3.3V
S9 LIMITER RESISTORS TO 3.3V
SOLENOID 2 SWITCH N-MOSFET
SOLENOID 1 SWITCH N-MOSFET
SX70 DISTRIBUTOR
openSX70 DONGLE or FLASH
v7.5
Design by Joaquín de Prada Creative Commons "Attribution-NonCommercial 4.0 International (CC BY-NC 4.0)" https://creativecommons.org/licenses/by-nc/4.0/
"MEROË-C" version
DEFAULT 6V ONLY 6V OR 3.3V NOT BOTH AT ONCE
MISO
SCK
RESET
MOSI
VF LED

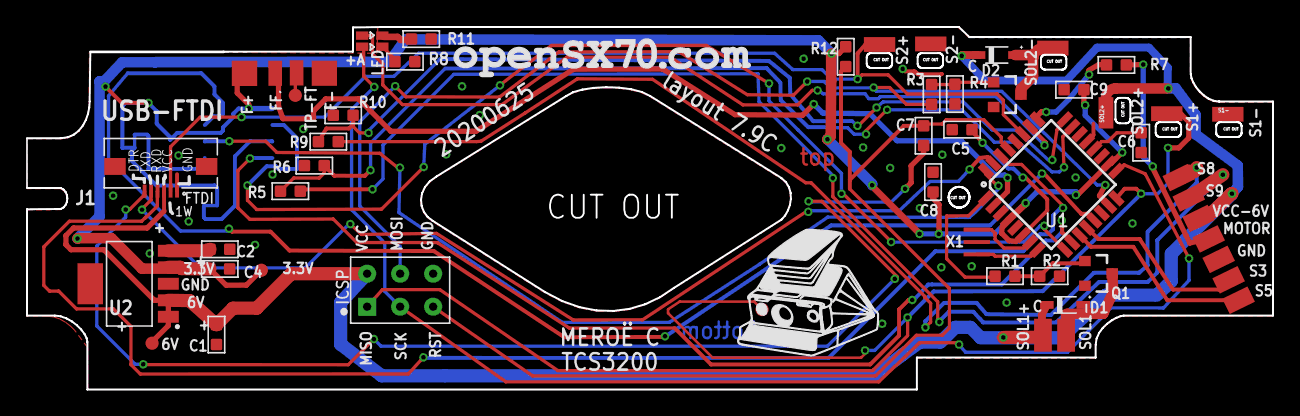
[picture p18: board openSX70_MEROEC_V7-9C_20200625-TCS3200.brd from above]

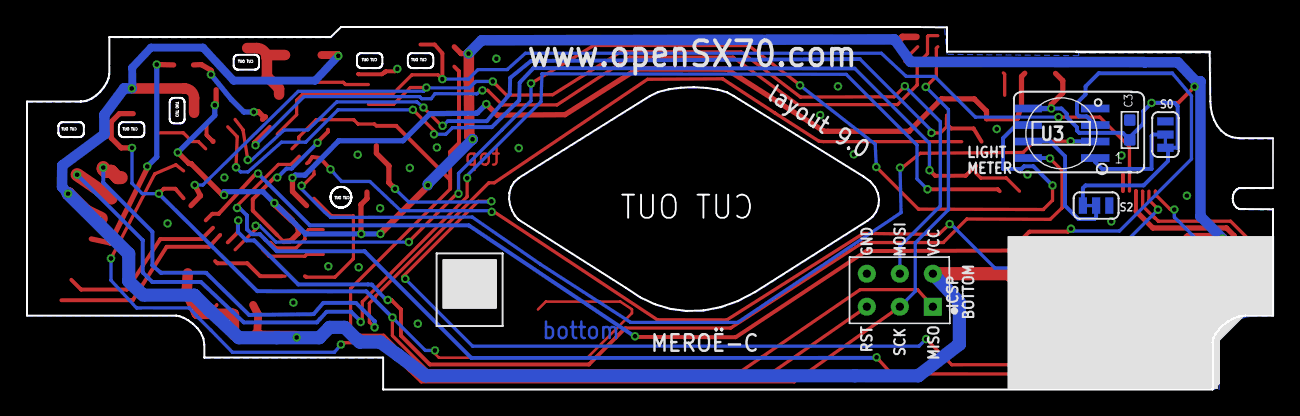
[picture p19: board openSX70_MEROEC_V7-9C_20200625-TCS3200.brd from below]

Board: 2 copper layers, 95.9 x 27.9 mm, 47 parts (4 on the bottom side), 39 nets.

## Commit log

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2017-11-27 initial commit of files
    These are the board and the schematic, initial design
    [openSX70_SCHEMATIC_COMPLETE.brd, openSX70_SCHEMATIC_COMPLETE.sch]
2017-11-27 the DXF outline files
    Files you import to create the Dimension layer on Eagle.
    [PCB_outline-SonarV2_tDOCU.dxf, PCB_outline-SonarV3_NEW_HOLE.dxf]
2017-11-27 more DXF outline files
    Updated DXF files. Not checked yet
    [PCB_outline-SonarV3_bDOCU_.dxf]
2017-11-27 Eagle schematic and board with connectors
    Eagle schematic and board with connectors. The components are not placed. Good start point to design your own board from scratch.
    [openSX70_SCHEMATIC_COMPLETE_NEW_BOARD_CONNECTORS.brd, openSX70_SCHEMATIC_COMPLETE_NEW_BOARD_CONNECTORS.sch]
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2017-11-27 Eagle main PCB 2.1
    Eagle main PCB 2.1, manufactured by EasyEDA as a test 26/11/2017
    [openSX70_SCHEMATIC_COMPLETE.brd]
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2017-12-16 New "RAW" as a startup for new placement/layout. Changed crystal for one smaller and with caps built in. Created files for new WIP.
    [openSX70_RAW_NEW_LAYOUT_20171216.brd, openSX70_RAW_NEW_LAYOUT_20171216.sch, openSX70_SCHEMATIC_COMPLETE_NEW_LAYOUT_20171216.brd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]
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2017-12-20 Changed MOTOR pin from 19 to 25. The board is a mess and I have to start over.
    [openSX70_SCHEMATIC_COMPLETE_NEW_LAYOUT_20171216.brd, openSX70_SCHEMATIC_COMPLETE_NEW_LAYOUT_20171216.sch]
2017-12-20 change MOTOR to pin 25 on RAW file.
    [openSX70_RAW_NEW_LAYOUT_20171216.brd, openSX70_RAW_NEW_LAYOUT_20171216.sch]
2017-12-20 new RAW version and WIP version with MOTOR+ to pin 25. RAW version without component layout on board to start from scratch.
    [openSX70_RAW_NEW_LAYOUT_20171220.brd, openSX70_RAW_NEW_LAYOUT_20171220.sch, openSX70_SCHEMATIC_COMPLETE.brd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]
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2017-12-21 minor updates in new layout. Routing manually important traces.
    [openSX70_WIP_NEW_LAYOUT_20171220.brd, openSX70_WIP_NEW_LAYOUT_20171220.sch]
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2017-12-25 Saved a pre-AR version and then different WIP AR.
    [openSX70_WIP_NEW_LAYOUT_20171225_V30_manually-routed-pre-AR.brd, openSX70_WIP_NEW_LAYOUT_20171225_V30_manually-routed-pre-AR.sch, openSX70_WIP_NEW_LAYOUT_20171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]
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2017-12-29 fixed connections on openSX70 library
    [openSX70_WIP_NEW_LAYOUT_20171220.brd, openSX70_WIP_NEW_LAYOUT_20171225_V30_manually-routed-pre-AR.brd, openSX70_WIP_NEW_LAYOUT_20171225_V30_manually-routed-pre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]
2018-01-02 V3.2 added license text. Will do to all brd.
    [openSX70_WIP_NEW_LAYOUT_20171229_V30_manually-routed-AR.brd, openSX70_WIP_NEW_LAYOUT_20171229_V30_manually-routed-AR.sch, openSX70_WIP_NEW_LAYOUT_20171229_V30_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]
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2018-01-03 Create new 3.4 "chocolate" version. Looks ok, will do more tests and send it for fabrication. Also created gerbers, remember minimun .8mm, better .6mm or .4mm.
    [openSX70_chocolate_V34_20180103_manually-routed-and-AR.brd, openSX70_chocolate_V34_20180103_manually-routed-and-AR.sch]
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2018-01-03 Added on copper top and bottom for sanity
    [openSX70_chocolate_V34_20180103_manually-routed-and-AR.brd]
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2018-01-03 fixed some stuff in the schematic
    [openSX70_chocolate_V341_20180103_manually-routed-and-AR.brd, openSX70_chocolate_V341_20180103_manually-routed-and-AR.sch]
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2018-01-03 Added correct version number in bottom
    [openSX70_chocolate_V341_20180103_manually-routed-and-AR.brd]
2018-01-16 New version 3.5, fixed D1 footprint and some tracks. Added an FTDI 3.3v-6V selection jumper. Change version name to cake
    [openSX70_CAKE_V35_20180116_manually-routed-and-AR.brd, openSX70_CAKE_V35_20180116_manually-routed-and-AR.sch, openSX70_chocolate_V35_20180116_manually-routed-a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]
2018-01-16 Lots of small fixes, and fixed cosmetically values, widening track and such.
    [openSX70_CAKE_V35_20180116_manually-routed-and-AR.brd]
2018-01-17 New version to fix Solenoid#1 pin error. Minor fix.
    [openSX70_CAKE_V36_20180117.brd, openSX70_CAKE_V36_20180117.sch]
2018-01-17 Minor 45º fixes ;-)
    [openSX70_CAKE_V36_20180117.brd]
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2018-01-17 Added a protection diode D1 to solenoid#1 for protection. I had assumed that it was built in the solenoid but Phyvine Tong indicated that some later models (alpha) don't have it.
    [openSX70_ALADDIN_V36_20180117.brd, openSX70_ALADDIN_V36_20180117.sch]
2018-01-17 Added GND 6V and 3.3V test points. Removed a bunch of innecessary vias.
    [openSX70_ALADDIN_V36_20180117.brd, openSX70_ALADDIN_V36_20180117.sch]
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2018-01-18 Added TP to pins 15 16 and 17, for bootloader programming (?)
    [openSX70_ALADDIN_V36_20180117.brd, openSX70_ALADDIN_V36_20180117.sch]
2018-01-18 Minor fixes, making the board look nicer.
    [openSX70_ALADDIN_V36_20180117.brd]
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2018-01-20 Trying a new component layout, saving the lens seal! NOT ROUTED use Aladdin for now
    [openSX70_LENS&BELLOWS_V40_20180120.brd, openSX70_LENS&BELLOWS_V40_20180120.sch, openSX70_LENS&BELLOWS_V50_20180120.brd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]
2018-01-22 Lost track of what I was doing, but basically trying to stay out of the light seal.
    [openSX70_LENS&BELLOWS_V50_20180120.brd]
2018-01-22 "Saved" Aladdin regarding light-seal issue. Will manufacture. Current 2.8
    [openSX70_ALADDIN_V38_20180122.GBL, openSX70_ALADDIN_V38_20180122.GBO, openSX70_ALADDIN_V38_20180122.GBP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]
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2018-01-22 Armonized all VIAS. Minor aesthetic fixes.
    [openSX70_ALADDIN_V38_20180122.brd]
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2018-01-23 New v.3.9 "Aladdin-fpc" is basically Aladdin with the FTDI header changed to the upper left in the form of a flexible cable.
    [openSX70_ALADDIN_V39_20180122.brd, openSX70_ALADDIN_V39_20180122.sch]
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2018-01-23 Minor changed to v.3.9 FPC with a flat cable .5mm for the FTDI. It is a variant based on the Aladdin v3.8
    [openSX70_ALADDIN_V39_20180122.brd]
2018-01-23 Fixing little things in all Aladdin boards
    [openSX70_ALADDIN_V38_20180122.brd, openSX70_ALADDIN_V38_20180122.sch, openSX70_ALADDIN_V39_20180122.brd]
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2018-01-24 Changed MISO/MOSI was all wrong
    [openSX70_ALADDIN_V38_20180122.GBL, openSX70_ALADDIN_V38_20180122.GBO, openSX70_ALADDIN_V38_20180122.GBP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]
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2018-02-09 Removed unnecessary vias, al pads. Minor fixes all over. Getting ready for production!
    [openSX70_ALADDIN_V395SEEED_20180208.brd]
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2018-02-10 Lots of changes in SEEED studio NOW 3.9.6S. Moved a lot of files to OLD folders.
    [openSX70_ALADDIN_V36_20180117.brd, openSX70_ALADDIN_V36_20180117.sch, openSX70_ALADDIN_V37_20180120.brd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]
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2018-02-20 Updated office to 8.6.3 minor changes. Rethinking buzzer altogether
    [openSX70_ALADDIN_V398SEEED_20180219.brd, openSX70_ALADDIN_V398SEEED_20180219.sch]
2018-02-21 retouches from home. Thinking about a buzzer fix, working on a 10-way FPC both ISCP and FTDI at once
    [openSX70_ALADDIN_V398B-SEEED_20180221.brd, openSX70_ALADDIN_V398B-SEEED_20180221.sch]
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2018-02-21 Latest with new Buzzer schematic
    [openSX70_ALADDIN_V398B-SEEED_20180221.brd, openSX70_ALADDIN_V398B-SEEED_20180221.sch]
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2018-02-22 New board nickname: Len's&Bellows 5.0 (different from Len's & Bellows 4.x): moved Atmega up, and much more little improvements!
    [openSX70_ALADDIN_V398C-SEEED_20180222.brd, openSX70_ALADDIN_V398C-SEEED_20180222.sch, openSX70_LENS&BELLOWS_V5.0-SEEED_20180222.brd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]
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2018-02-26 Latest versions bypassing Sourcetree
    SourceTree not working from home, tried everything to no avail.
    [openSX70_LENS&BELLOWS_V5.1-SEEED_20180224.brd, openSX70_LENS&BELLOWS_V5.1-SEEED_20180224.sch]
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2018-05-23 New 5,5 "Pathfinder" with relocated BH1750 and removed buzzer.
    [openSX70_PATHFINDER_V5.5-SEEED_20180522.brd, openSX70_PATHFINDER_V5.5-SEEED_20180522.sch]
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2018-10-09 new experimental 6.2: I find no way to fit the FPC connector oposite on the PCB of where it is now, there is just no space.
    [openSX70_ALPHA_V6.2-20181009.brd, openSX70_ALPHA_V6.2-20181009.sch]
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2018-10-31 new 7-pad (fixed the component) and WIP on the LED, new LED dual SMD
    [openSX70_ALPHA_V6.5-20181015.brd, openSX70_ALPHA_V6.5-20181015.sch]
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2018-11-04 minor fixes or picture graphic
    [openSX70_ALPHA_V6-2-3-20181104.brd]
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2018-12-21 new main PCB fixed 3rd resistor on Photodiode!
    [openSX70_ALPHA_V6-2-5-20181220.brd, openSX70_ALPHA_V6-2-5-20181220.sch]
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2021-01-29 Latest PCBs that I feel confident to push. Contact me if doubts.
    [openSX70_SONAR-FBW_8-9-3-8-S4-TCS3200-NO-THERMAL-20200509.brd, openSX70_SONAR-FBW_8-9-3-8-S4-TCS3200-NO-THERMAL-20200509.sch, openSX70_SONAR_8-9-3-8-S4-TCS3200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]

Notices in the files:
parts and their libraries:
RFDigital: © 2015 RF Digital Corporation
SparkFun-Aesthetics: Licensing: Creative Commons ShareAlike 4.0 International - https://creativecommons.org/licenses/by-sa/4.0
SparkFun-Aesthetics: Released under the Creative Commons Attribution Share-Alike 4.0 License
